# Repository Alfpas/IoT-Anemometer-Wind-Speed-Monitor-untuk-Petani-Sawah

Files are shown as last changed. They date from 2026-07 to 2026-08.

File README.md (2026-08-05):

# 🌬️ IoT Anemometer — Wind Speed Monitor untuk Petani di Sawah

Sistem monitoring kecepatan angin berbasis IoT yang dirancang untuk membantu petani sawah memantau kondisi angin di lahan mereka secara real-time. Data dikirim dari sensor di lapangan ke dashboard web melalui MQTT.

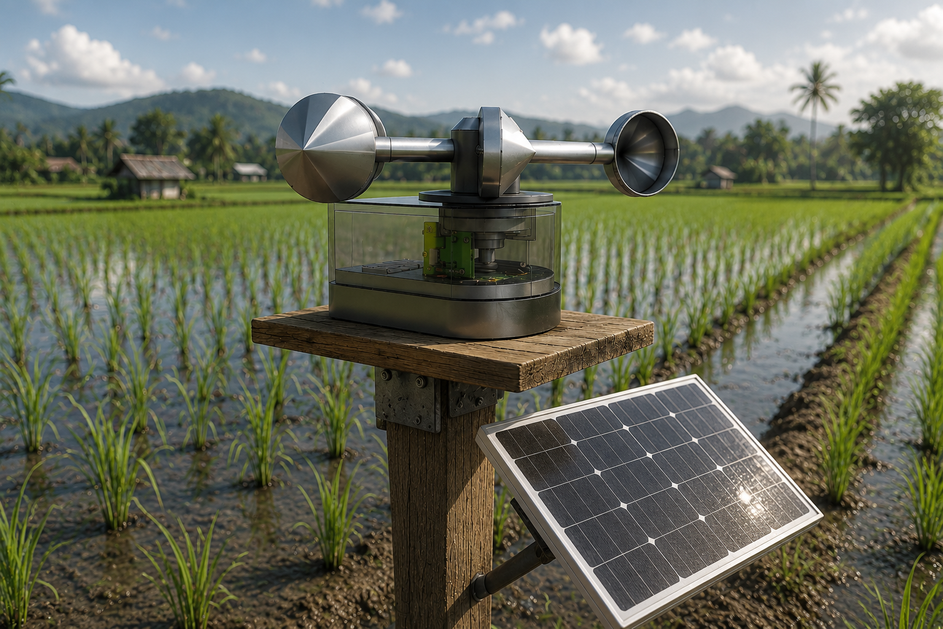
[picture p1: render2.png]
Deployment di Sawah


## 📋 Fitur

- Pengukuran kecepatan angin real-time menggunakan sensor cup-type anemometer (HC-020K)
- Pengiriman data via MQTT (TLS/secure) ke EMQX Cloud
- Dashboard web real-time menggunakan Socket.io
- Indikator status LED pada perangkat (connecting, standby, sending, error)
- Desain enclosure tahan lapangan dengan panel surya

## 🏗️ Arsitektur Sistem

```
[ Anemometer + ESP32 ]
         |
         | MQTT (TLS, port 8883)
         v
[ EMQX Cloud Broker ]
         |
         | Subscribe topic
         v
[ Backend Node.js (Express + Socket.io) ]
         |
         | WebSocket
         v
[ Dashboard Web (Browser) ]
```

## 🔧 Hardware

| Komponen | Keterangan |
|---|---|
| Mikrokontroler | ESP32 |
| Sensor kecepatan | HC-020K (speed sensor / slotted disc) |
| Konektivitas | WiFi |
| Catu daya | Panel surya + baterai |
| Enclosure | 3d Print |

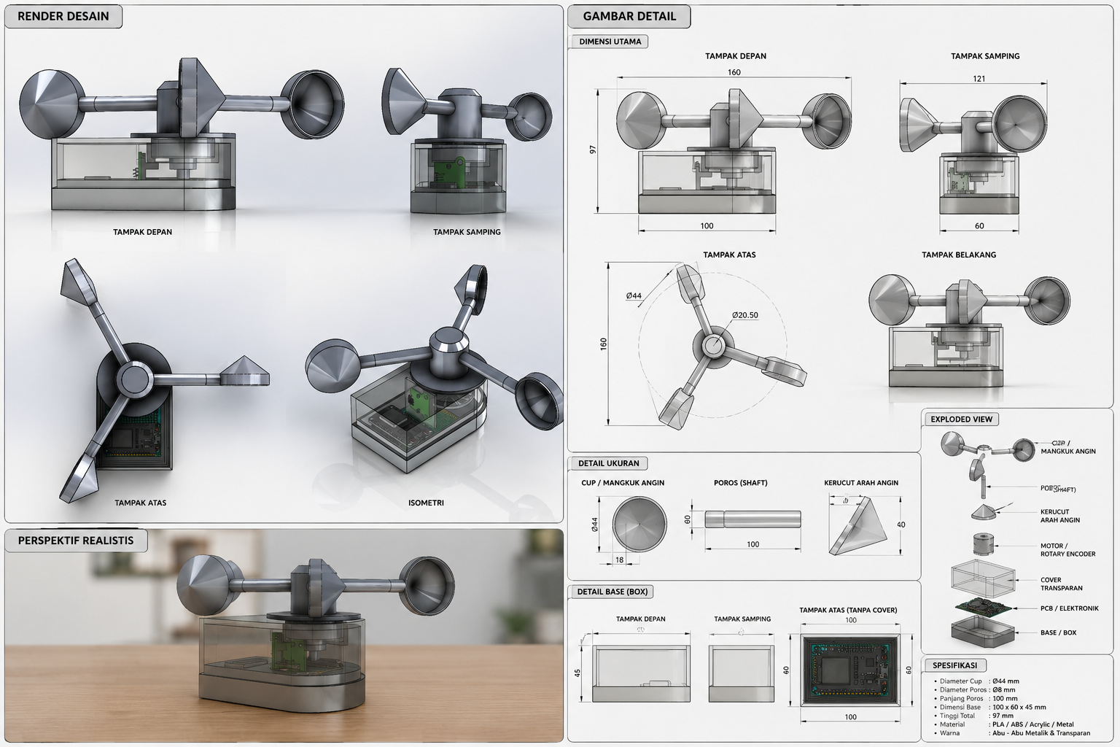
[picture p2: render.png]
CAD Render Anemometer


## 📂 Struktur Folder

```
anemometer-iot/
├── app/          # Backend web (Node.js + Express + Socket.io)
│   ├── server.js
│   └── public/
├── stl/          # File 3D print (STL) untuk enclosure & cup anemometer
├── firmware/      # Kode ESP32 (.ino)
└── img/          # Dokumentasi visual (render CAD, foto deployment)
```

## ⚙️ Konfigurasi

### 1. Firmware (ESP32)

Edit bagian berikut di kode `.ino` sebelum upload:

```cpp
const char* ssid = "NAMA_WIFI";
const char* password = "PASSWORD_WIFI";

const char* mqtt_server = "xxxxxxx.ala.asia-southeast1.emqxsl.com";
const int mqtt_port = 8883;

const char* mqtt_user = "anemometer_esp1";
const char* mqtt_pass = "your_password";

const char* topic = "weather/anemometer";
```

Pastikan root CA certificate dari EMQX Cloud sudah dimasukkan ke variabel `root_ca` di kode.

**Library yang dibutuhkan (Arduino IDE):**
- `WiFi.h`
- `WiFiClientSecure.h`
- `PubSubClient`
- `ArduinoJson`

### 2. Backend Web

```bash
cd app
npm install express socket.io mqtt
node server.js
```

Buka `http://localhost:3000` di browser untuk melihat dashboard real-time.

## 📡 Format Data (MQTT Payload)

Data dikirim dalam format JSON tiap 1 detik ke topic `weather/anemometer`:

```json
{
  "pulse": 24,
  "rpm": 144.0,
  "speed_ms": 3.98,
  "speed_kmh": 14.33
}
```

## 💡 Indikator LED Status

| Pola LED | Arti |
|---|---|
| Kedip cepat | Sedang menghubungkan (WiFi/MQTT) |
| Kedip pelan | WiFi tersambung, MQTT belum |
| Mati | Sistem normal, standby |
| Kedip singkat sesekali | Data berhasil dikirim |
| Tiga kedip cepat | Pengiriman data gagal |
| Menyala terus | Gangguan koneksi (gagal berkali-kali) |

## 🚀 Status Project

✅ Firmware ESP32 berjalan dan berhasil mengirim data ke EMQX Cloud <br>
✅ Backend web menerima data real-time via MQTT<br>
🔲 Penambahan sensor tambahan (suhu, kelembapan, kelembapan tanah) — direncanakan<br>
🔲 Deployment jangka panjang di lahan sawah<br>

## 📄 Lisensi

Proyek ini dilisensikan di bawah **MIT License** — bebas digunakan, dimodifikasi, dan didistribusikan dengan menyertakan kredit.

```
MIT License © 2026 Alfredo
```

---

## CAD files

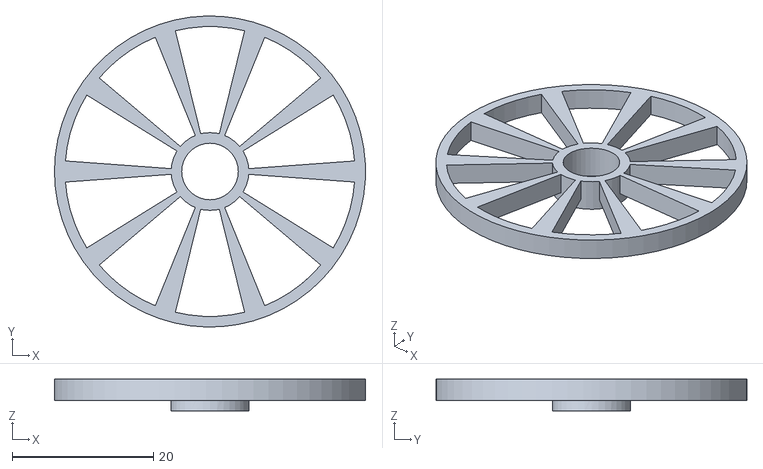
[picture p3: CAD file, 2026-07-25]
STL/rodaaa.STL
44.0 x 44.0 x 4.50

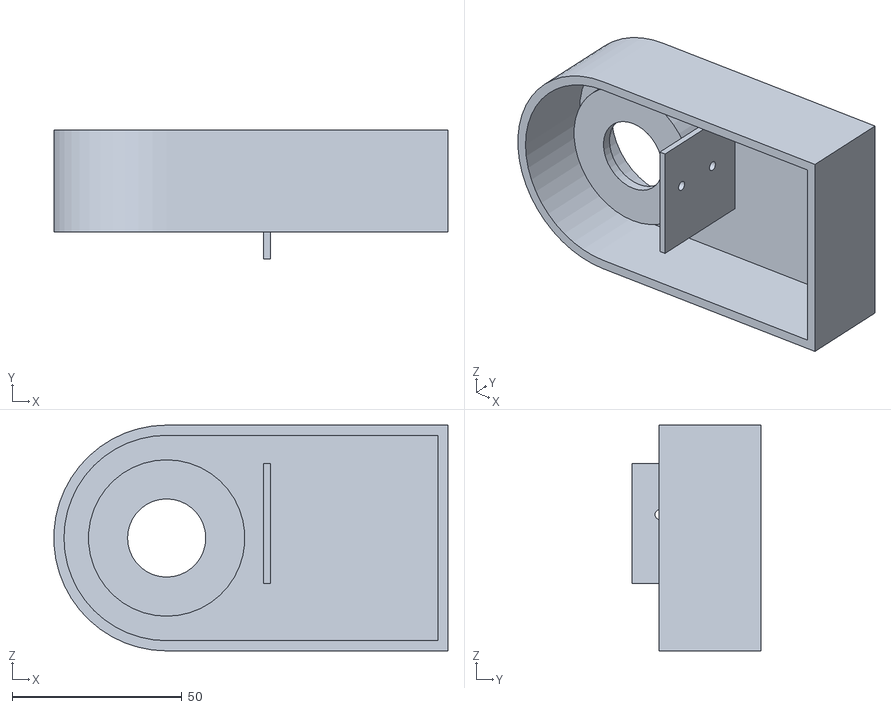
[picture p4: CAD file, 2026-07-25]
STL/base1.STL
115.9 x 38.0 x 66.4

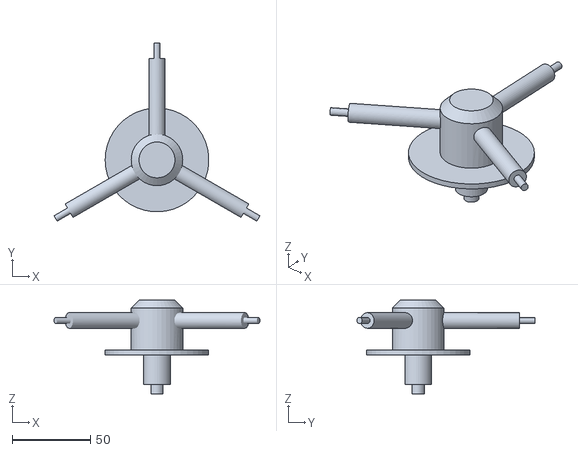
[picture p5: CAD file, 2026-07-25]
STL/as.STL
131.9 x 114.2 x 60.0

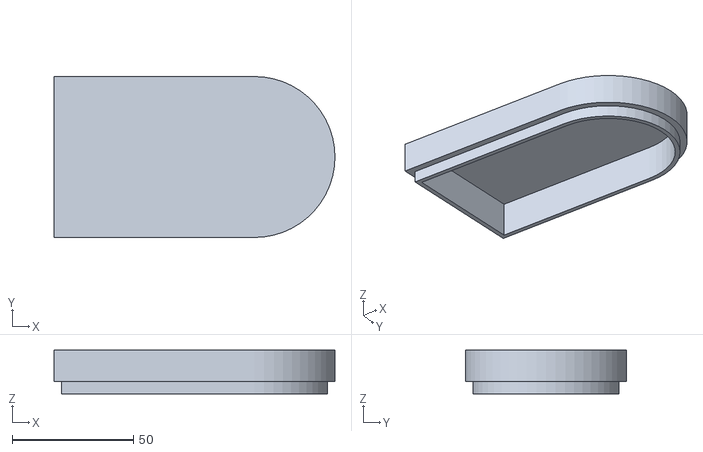
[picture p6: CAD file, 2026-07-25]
STL/base2.STL
116.0 x 66.4 x 18.0

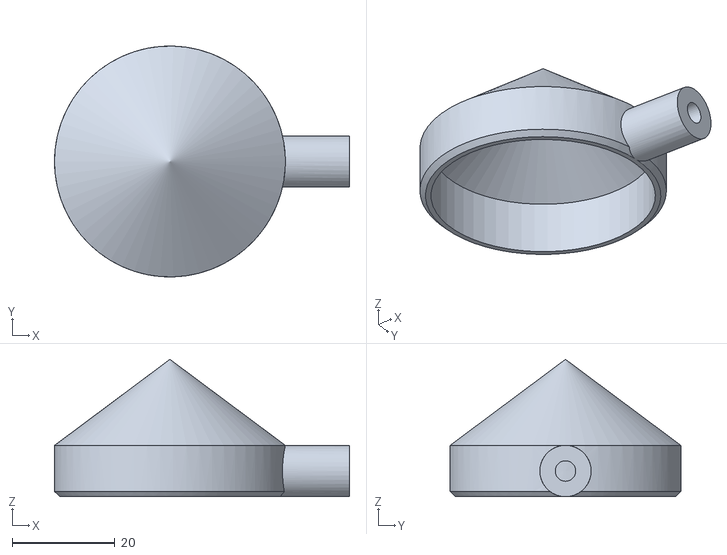
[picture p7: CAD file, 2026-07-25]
STL/cop.STL
57.5 x 45.0 x 26.8

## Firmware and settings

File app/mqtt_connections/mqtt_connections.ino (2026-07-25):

#include <WiFi.h>
#include <WiFiClientSecure.h>
#include <PubSubClient.h>
#include <ArduinoJson.h>

//=========================
// WIFI
//=========================
const char* ssid = "Pasca Sarjana";
const char* password = "ublkecee";

//=========================
// MQTT
//=========================
const char* mqtt_server = "t2a21271.ala.asia-southeast1.emqxsl.com";
const int mqtt_port = 8883;

const char* mqtt_user = "anemometer_esp1";
const char* mqtt_pass = "esp12345678";

const char* topic = "weather/anemometer";

//=========================
// LED STATUS
//=========================
#define LED_STATUS 2

int mqttFailCount = 0;
const int MQTT_FAIL_THRESHOLD = 5; // setelah 5x gagal beruntun -> LED nyala terus

//=========================
// CA CERTIFICATE
// Ganti dengan isi file .crt
//=========================
const char* root_ca =
"-----BEGIN CERTIFICATE-----\n"
"MIIDjjCCAnagAwIBAgIQAzrx5qcRqaC7KGSxHQn65TANBgkqhkiG9w0BAQsFADBh\n"
"MQswCQYDVQQGEwJVUzEVMBMGA1UEChMMRGlnaUNlcnQgSW5jMRkwFwYDVQQLExB3\n"
"d3cuZGlnaWNlcnQuY29tMSAwHgYDVQQDExdEaWdpQ2VydCBHbG9iYWwgUm9vdCBH\n"
"MjAeFw0xMzA4MDExMjAwMDBaFw0zODAxMTUxMjAwMDBaMGExCzAJBgNVBAYTAlVT\n"
"MRUwEwYDVQQKEwxEaWdpQ2VydCBJbmMxGTAXBgNVBAsTEHd3dy5kaWdpY2VydC5j\n"
"b20xIDAeBgNVBAMTF0RpZ2lDZXJ0IEdsb2JhbCBSb290IEcyMIIBIjANBgkqhkiG\n"
"9w0BAQEFAAOCAQ8AMIIBCgKCAQEAuzfNNNx7a8myaJCtSnX/RrohCgiN9RlUyfuI\n"
"2/Ou8jqJkTx65qsGGmvPrC3oXgkkRLpimn7Wo6h+4FR1IAWsULecYxpsMNzaHxmx\n"
"1x7e/dfgy5SDN67sH0NO3Xss0r0upS/kqbitOtSZpLYl6ZtrAGCSYP9PIUkY92eQ\n"
"q2EGnI/yuum06ZIya7XzV+hdG82MHauVBJVJ8zUtluNJbd134/tJS7SsVQepj5Wz\n"
"tCO7TG1F8PapspUwtP1MVYwnSlcUfIKdzXOS0xZKBgyMUNGPHgm+F6HmIcr9g+UQ\n"
"vIOlCsRnKPZzFBQ9RnbDhxSJITRNrw9FDKZJobq7nMWxM4MphQIDAQABo0IwQDAP\n"
"BgNVHRMBAf8EBTADAQH/MA4GA1UdDwEB/wQEAwIBhjAdBgNVHQ4EFgQUTiJUIBiV\n"
"5uNu5g/6+rkS7QYXjzkwDQYJKoZIhvcNAQELBQADggEBAGBnKJRvDkhj6zHd6mcY\n"
"1Yl9PMWLSn/pvtsrF9+wX3N3KjITOYFnQoQj8kVnNeyIv/iPsGEMNKSuIEyExtv4\n"
"NeF22d+mQrvHRAiGfzZ0JFrabA0UWTW98kndth/Jsw1HKj2ZL7tcu7XUIOGZX1NG\n"
"Fdtom/DzMNU+MeKNhJ7jitralj41E6Vf8PlwUHBHQRFXGU7Aj64GxJUTFy8bJZ91\n"
"8rGOmaFvE7FBcf6IKshPECBV1/MUReXgRPTqh5Uykw7+U0b6LJ3/iyK5S9kJRaTe\n"
"pLiaWN0bfVKfjllDiIGknibVb63dDcY3fe0Dkhvld1927jyNxF1WW6LZZm6zNTfl\n"
"MrY=\n"
"-----END CERTIFICATE-----\n";

//=========================
// HC020K
//=========================
#define SENSOR_PIN 13

volatile unsigned long pulseCount = 0;

WiFiClientSecure espClient;
PubSubClient client(espClient);

//=========================
// PARAMETER
//=========================
const int SLOT = 10;

const float RADIUS = 0.044;          // meter

const float CALIBRATION = 2.40;

unsigned long lastMillis = 0;

//=========================
// INTERRUPT
//=========================
void IRAM_ATTR countPulse()
{
    pulseCount++;
}

//=========================
// LED HELPER
//=========================
void ledBlinkOnceShort()
{
    // kedip singkat -> data berhasil terkirim
    digitalWrite(LED_STATUS, HIGH);
    delay(50);
    digitalWrite(LED_STATUS, LOW);
}

void ledBlinkFail3x()
{
    // tiga kedip cepat -> pengiriman gagal
    for (int i = 0; i < 3; i++)
    {
        digitalWrite(LED_STATUS, HIGH);
        delay(100);
        digitalWrite(LED_STATUS, LOW);
        delay(100);
    }
}

//=========================
// WIFI
//=========================
void connectWiFi()
{
    Serial.print("Connecting WiFi");

    WiFi.begin(ssid, password);

    while (WiFi.status() != WL_CONNECTED)
    {
        // berkedip cepat -> sedang menghubungkan
        digitalWrite(LED_STATUS, HIGH);
        delay(100);
        digitalWrite(LED_STATUS, LOW);
        delay(100);

        Serial.print(".");
    }

    Serial.println();
    Serial.println("WiFi Connected");

    digitalWrite(LED_STATUS, LOW); // standby sementara nunggu MQTT
}

//=========================
// MQTT
//=========================
void reconnectMQTT()
{
    while (!client.connected())
    {
        Serial.print("Connecting MQTT...");

        // berkedip cepat -> sedang menghubungkan
        digitalWrite(LED_STATUS, HIGH);
        delay(100);
        digitalWrite(LED_STATUS, LOW);
        delay(100);

        if(client.connect("ESP32_Anemometer", mqtt_user, mqtt_pass))
        {
            Serial.println("Connected");

            mqttFailCount = 0;
            digitalWrite(LED_STATUS, LOW); // mati -> sistem normal, standby
        }
        else
        {
            Serial.print("Failed : ");
            Serial.println(client.state());

            mqttFailCount++;

            if (mqttFailCount >= MQTT_FAIL_THRESHOLD)
            {
                // menyala terus -> gangguan koneksi (gagal berkali-kali)
                digitalWrite(LED_STATUS, HIGH);
                delay(3000);
            }
            else
            {
                // berkedip pelan -> WiFi tersambung, MQTT belum
                digitalWrite(LED_STATUS, HIGH);
                delay(1500);
                digitalWrite(LED_STATUS, LOW);
                delay(1500);
            }
        }
    }
}

//=========================
// SETUP
//=========================
void setup()
{
    Serial.begin(115200);

    pinMode(LED_STATUS, OUTPUT);
    digitalWrite(LED_STATUS, LOW);

    pinMode(SENSOR_PIN, INPUT_PULLUP);

    attachInterrupt(
        digitalPinToInterrupt(SENSOR_PIN),
        countPulse,
        FALLING
    );

    connectWiFi();

    espClient.setCACert(root_ca);

    client.setServer(mqtt_server, mqtt_port);
}

//=========================
// LOOP
//=========================
void loop()
{
    if(WiFi.status()!=WL_CONNECTED)
        connectWiFi();

    if(!client.connected())
        reconnectMQTT();

    client.loop();

    if(millis()-lastMillis>=1000)
    {
        noInterrupts();

        unsigned long pulse = pulseCount;

        pulseCount = 0;

        interrupts();

        //-----------------------
        // RPM
        //-----------------------
        float rpm =
            (pulse * 60.0) / SLOT;

        //-----------------------
        // Tip Speed
        //-----------------------
        float tipSpeed =
            (2.0 * PI * RADIUS * rpm) / 60.0;

        //-----------------------
        // Wind Speed
        //-----------------------
        float windSpeed =
            tipSpeed * CALIBRATION;

        float kmh =
            windSpeed * 3.6;

        //-----------------------
        // JSON
        //-----------------------
        StaticJsonDocument<256> doc;

        doc["pulse"] = pulse;
        doc["rpm"] = rpm;
        doc["speed"] = windSpeed;
        doc["speed_ms"] = windSpeed;
        doc["speed_kmh"] = kmh;

        char buffer[256];

        serializeJson(doc, buffer);

        bool sent = client.publish(topic, buffer);

        if (sent)
        {
            ledBlinkOnceShort();  // kedip singkat -> data berhasil dikirim
        }
        else
        {
            ledBlinkFail3x();     // tiga kedip cepat -> pengiriman gagal
        }

        //-----------------------
        // Serial Monitor
        //-----------------------
        Serial.println("====================");
        Serial.print("Pulse : ");
        Serial.println(pulse);

        Serial.print("RPM : ");
        Serial.println(rpm);

        Serial.print("Wind : ");
        Serial.print(windSpeed);
        Serial.println(" m/s");

        Serial.print("KMH : ");
        Serial.println(kmh);

        lastMillis = millis();
    }
}
